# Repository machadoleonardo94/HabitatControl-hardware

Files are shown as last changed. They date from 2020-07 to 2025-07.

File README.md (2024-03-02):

## Hardware files for running HabitatControl Firmware
### ** Version 1 contains 5 PWM open drain channels, 2 NO relay channels, I2C 1" OLED display and DHT22 humidity and temperature sensor;
### ** Version 3 contains 6 PWM 700mA current limited LED drivers and I2C 1" OLED display
### Both versions are controlled via webserver for schedule of light intensity and data sampling





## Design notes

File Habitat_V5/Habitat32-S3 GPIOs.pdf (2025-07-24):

Features:
- Microcontrolador ESP32-S3-WROOM
- 2 Canais PWM 705mA CC XL4001
- 4 Canais PWM 620mA CC XL4001
- 1 Canal PWM Dreno aberto 10A
- 1 Enable master p/ drivers
- 1 Sensor 1Wire Temperatura DS18B20
- LED Debug WS2812B + Saída 5V 600mA
- Sem horário
- Sem internet
- Manual
- Automático
- I2C 1
- Display 3V3 (0x3C)
- ADS1115 (0x48)
■ Tensão de entrada atenuado 11x ■ Nível de fluído pull-up 330
■ Alerta fluído baixo pull-up 2k2
■ Livre pull-up 2k2
- SHT40 (0x44)
■ Temperatura ±0.2 ºC
■ Umidade ±1.8%
- RTC (0x68)
- I2C 2
- Display 5V (0xFF)

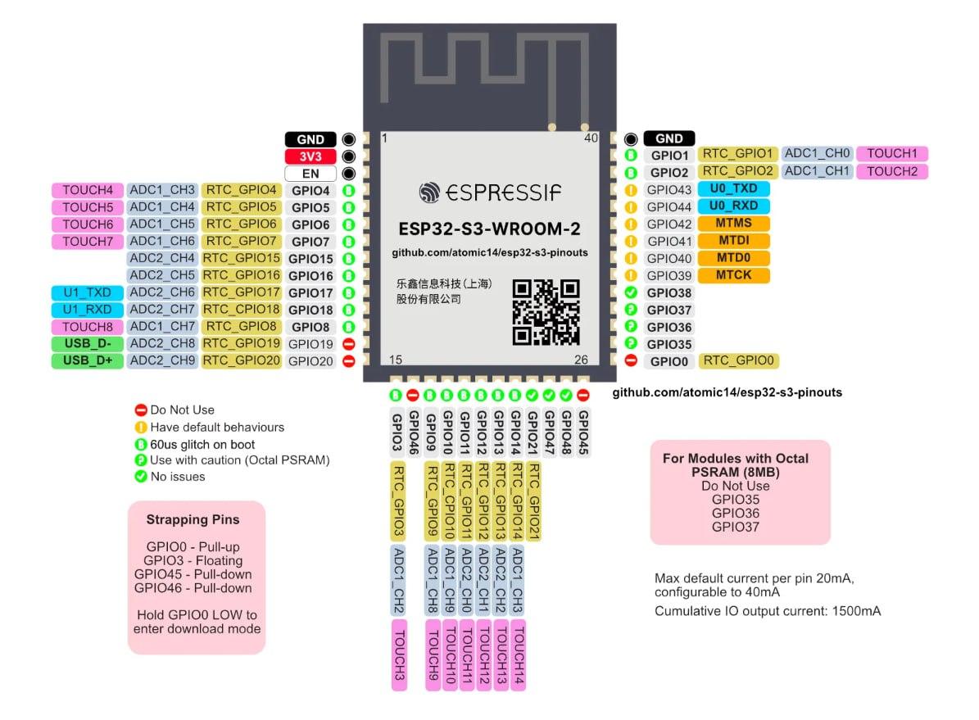
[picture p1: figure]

IO | Input | Output | Use | Notes
0 | 10k UP | OK | Prog | Boot mode, 60us glitch on boot
1 | OK | OK | | 60us glitch on boot
2 | OK | OK | | 60us glitch on boot
3 | Floating | X | X | Strapping, 60us glitch on boot
4 | OK | OK | CH1 | 60us glitch on boot
5 | OK | OK | CH2 | 60us glitch on boot
6 | OK | OK | CH3 | 60us glitch on boot
7 | OK | OK | CH4 | 60us glitch on boot
8 | OK | OK | I2C SCL 2 | 60us glitch on boot
9 | OK | OK | I2C SDA 2 | 60us glitch on boot
10 | OK | OK | I2C SCL 1 | 60us glitch on boot
11 | OK | OK | I2C SDA 1 | 60us glitch on boot
12 | OK | OK | Opto | 60us glitch on boot
13 | OK | OK | 1Wire | 60us glitch on boot
14 | OK | OK | CH7 | 60us glitch on boot
15 | OK | OK | CH5 | 60us glitch on boot
16 | OK | OK | CH6 | 60us glitch on boot
17 | OK | OK | WS2812B | 60us glitch on boot
18 | OK | OK | Free | 60us glitch on boot
19 | OK | OK | USB D- | Do not use as GPIO
20 | OK | OK | USB D+ | Do not use as GPIO
21 | OK | OK | Relay 1 | Stable GPIO
35 | Floating | X | PSRAM | Embedded RAM
36 | Floating | X | PSRAM | Embedded RAM
37 | Floating | X | PSRAM | Embedded RAM
38 | OK | OK | Enable Master | Stable GPIO
39 | X | X | X | MTCK

40 | X | X | X | MTDO
41 | X | X | X | MTDI
42 | X | X | X | MTMS
43 | OK | X | TX | Reserved TX
44 | | OK | RX | Reserved RX
45 | Floating | X | X | Strapping
46 | Floating | X | X | Strapping
47 | OK | OK | Free | Stable GPIO
48 | OK | OK | Free | Stable GPIO

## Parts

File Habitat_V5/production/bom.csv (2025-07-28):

Designator | Footprint | Quantity | Value | LCSC Part #
C1, C10, C11, C12, C13, C14, C15, C16, C17, C19, C20, C21, C23, C24, C25, C3, C4, C5, C6, C9 | C_Elec_6.3x7.7 | 20 | 220uF | C7471881
C2, CD2, CD4, CD5, CD7, CD8 | 0805 | 6 | 10u | C77075
C22 | C_Elec_6.3x7.7 | 1 | 100uF | C99837
C26, CD6 | 0805 | 2 | 100n | C1711
C7, C8, CD1, CD3 | 0805 | 4 | 100n | C2909631
D1 | LED_WS2812B_PLCC4_5.0x5.0mm_P3.2mm | 1 | WS2812B | 1
D10, D12, D13, D14, D16, D3, D8, D9 | D_SMA | 8 | SS14 | C2909920
D11, D4, D6 | 0805 | 3 | LED | C84256
D15, D5, D7 | D_SOD-123 | 3 | 1N4148W | C82544
D17, D18, D19, D20 | SOT-23 | 4 | BAT54S | C47546
D2 | D_MiniMELF | 1 | D_Zener | C181075
F1 | 1206 | 1 | Polyfuse | C22446878
J1, J3, J4 | PhoenixContact_MSTBA_2,5_4-G-5,08_1x04_P5.08mm_Horizontal | 3 | Conn_01x04_Socket
J2, J5, RELAY1 | PhoenixContact_MSTBA_2,5_3-G-5,08_1x03_P5.08mm_Horizontal | 3 | Conn_01x03_Socket
K1 | Relay_SPDT_Hongfa_JQC-3FF_0XX-1Z | 1 | Relay_SPDT
L1, L3, L4, L5, L6, L7, L8 | L_Sunlord_SWPA4010S | 7 | 33u | C167885
L2 | 0805 | 1 | 22n | C167885
OLED1, OLED2, SERIAL1 | Hirose_DF13C_CL535-0404-8-51_1x04-1MP_P1.25mm_Vertical | 3 | Conn_01x04_Socket | C7433470
OPTO1 | PhoenixContact_MSTBA_2,5_3-G-5,08_1x03_P5.08mm_Horizontal | 1 | Conn_01x03_Pin | 1
PROG1, RST1 | SW_SPST_PTS647_Sx38 | 2 | SW_Push | C455246
PWM1, S1, S2, TH1, VDC2 | PhoenixContact_MSTBA_2,5_2-G-5,08_1x02_P5.08mm_Horizontal | 5 | Conn_01x02_Pin | 1
Q1 | SOT-223-3_TabPin2 | 1 | PMOS | C154901
Q10, Q11, Q12, Q13, Q14, Q15, Q16, Q17, Q2, Q4, Q5, Q6, Q7, Q8, Q9 | SOT-23 | 15 | 2N7002K | C65189
Q3 | TO-252-2 | 1 | 40N02
R1, R10, R12, R13, R20, R25, R26, R27, R29, R32, R33, R34, R35, R36, R37, R38, R39, R40, R41, R42, R43, R44, R8 | 0805 | 23 | 10k | C17414
R11, R14, R16, R19 | 1206 | 4 | 0R22 | C2683384
R15, R24, R30, R31 | 0805 | 4 | 330 | C17630
R17, R18 | 1206 | 2 | 0R25 | C2932845
R2, R9 | 0805 | 2 | 1k | C95781
R21, R23, R3, R4, R5, R6, R7 | 0805 | 7 | 2k2 | C17520
R22, R28 | 0805 | 2 | 100k | C149504
RTC1 | RTC | 1 | Conn_01x04_Socket | 1
SHT40 | PinHeader_1x04_P2.54mm_Vertical | 1 | Conn_01x04_Socket | 1
U1 | SOIC-8_3.9x4.9mm_P1.27mm | 1 | XL1509-5V | C2681227
U10, U4, U5, U7, U8, U9 | ESOP-8_L4.9-W3.9-P1.27-LS6.0-BL-EP | 6 | ~ | C2988027
U11 | TSSOP-10_3x3mm_P0.5mm | 1 | ADS1115IDGS | C37593
U2 | SOT-23-5 | 1 | AP2112K-3.3 | C51118
U3 | SMDIP-4_W7.62mm | 1 | PC817 | C5451664
U6 | ESP32-S3-WROOM-1 | 1 | ESP32-S3-WROOM-1
VDC1 | BarrelJack_Horizontal | 1 | Barrel_Jack_Switch | C720557

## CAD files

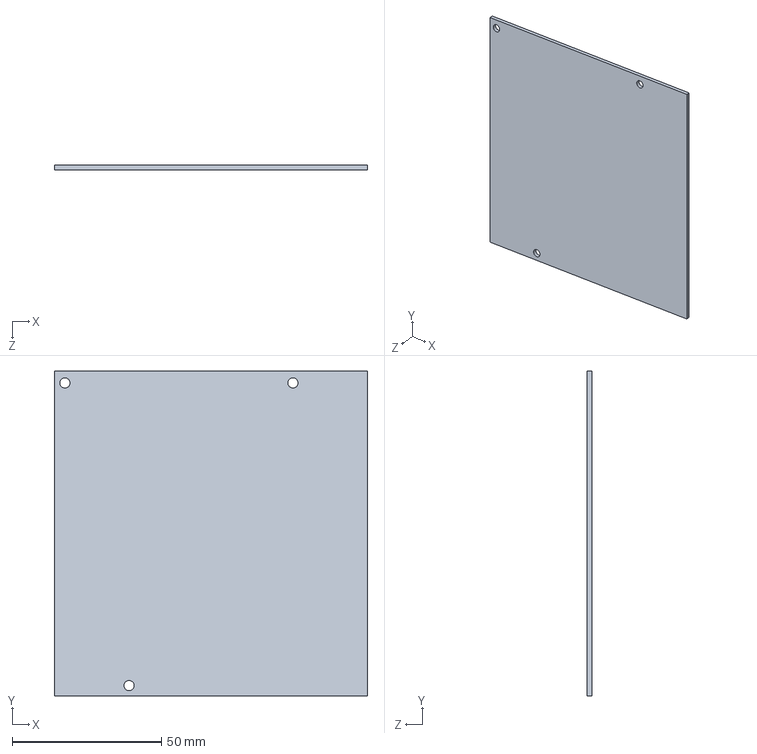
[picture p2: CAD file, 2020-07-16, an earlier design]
Habitat_V1/HabitatControl-noholes.step
105.0 x 109.0 x 1.59 mm

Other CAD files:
Habitat_V1/HabitatControl.step

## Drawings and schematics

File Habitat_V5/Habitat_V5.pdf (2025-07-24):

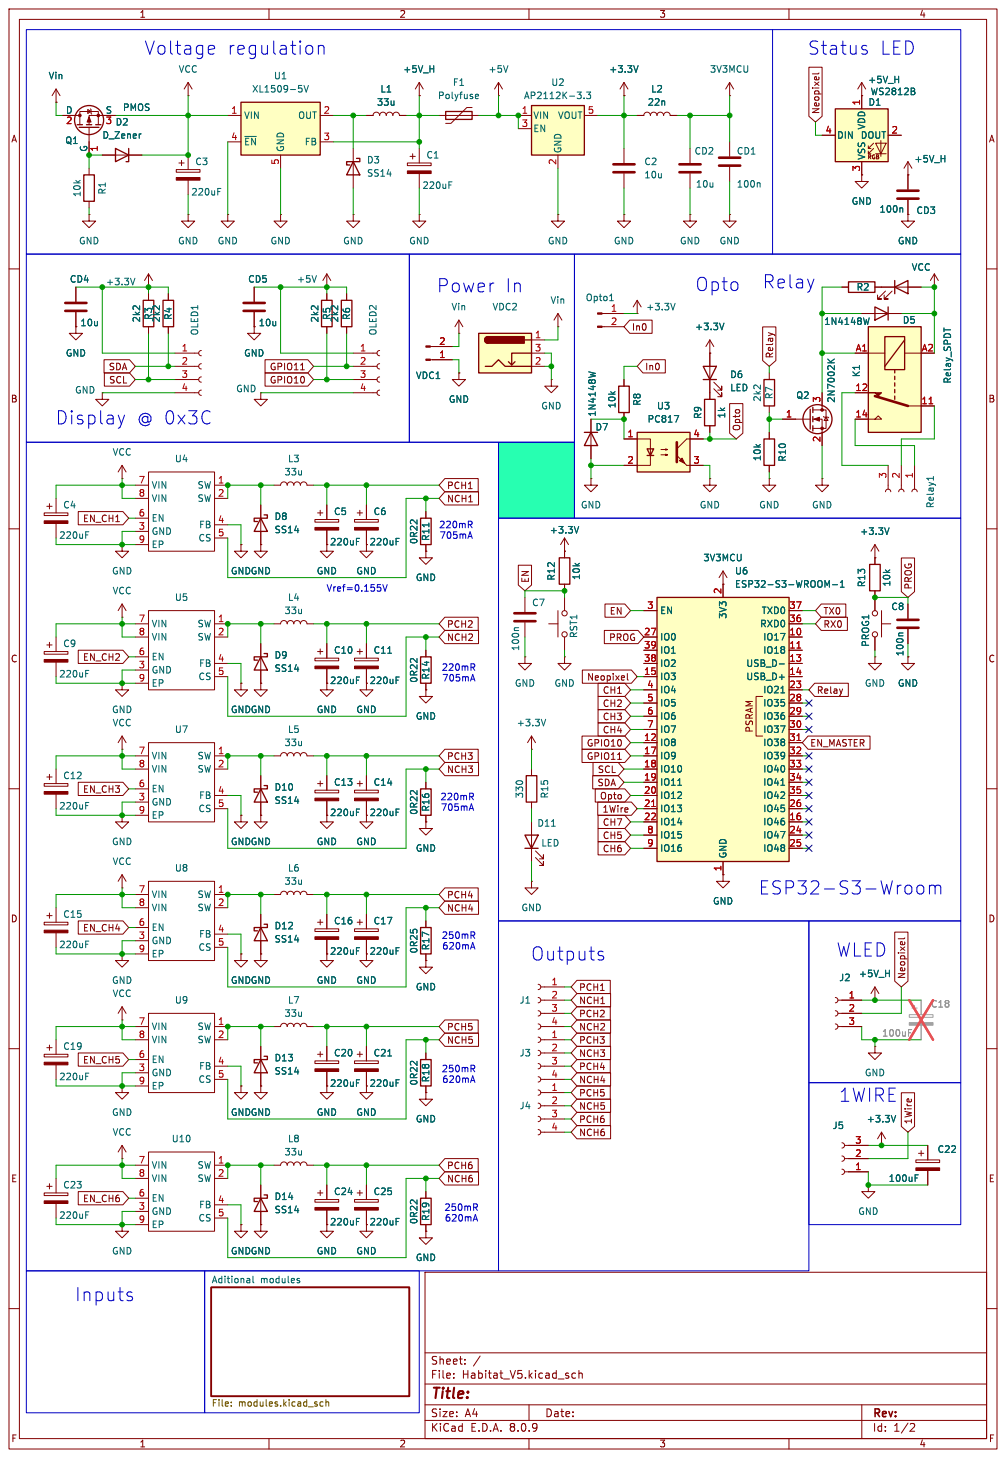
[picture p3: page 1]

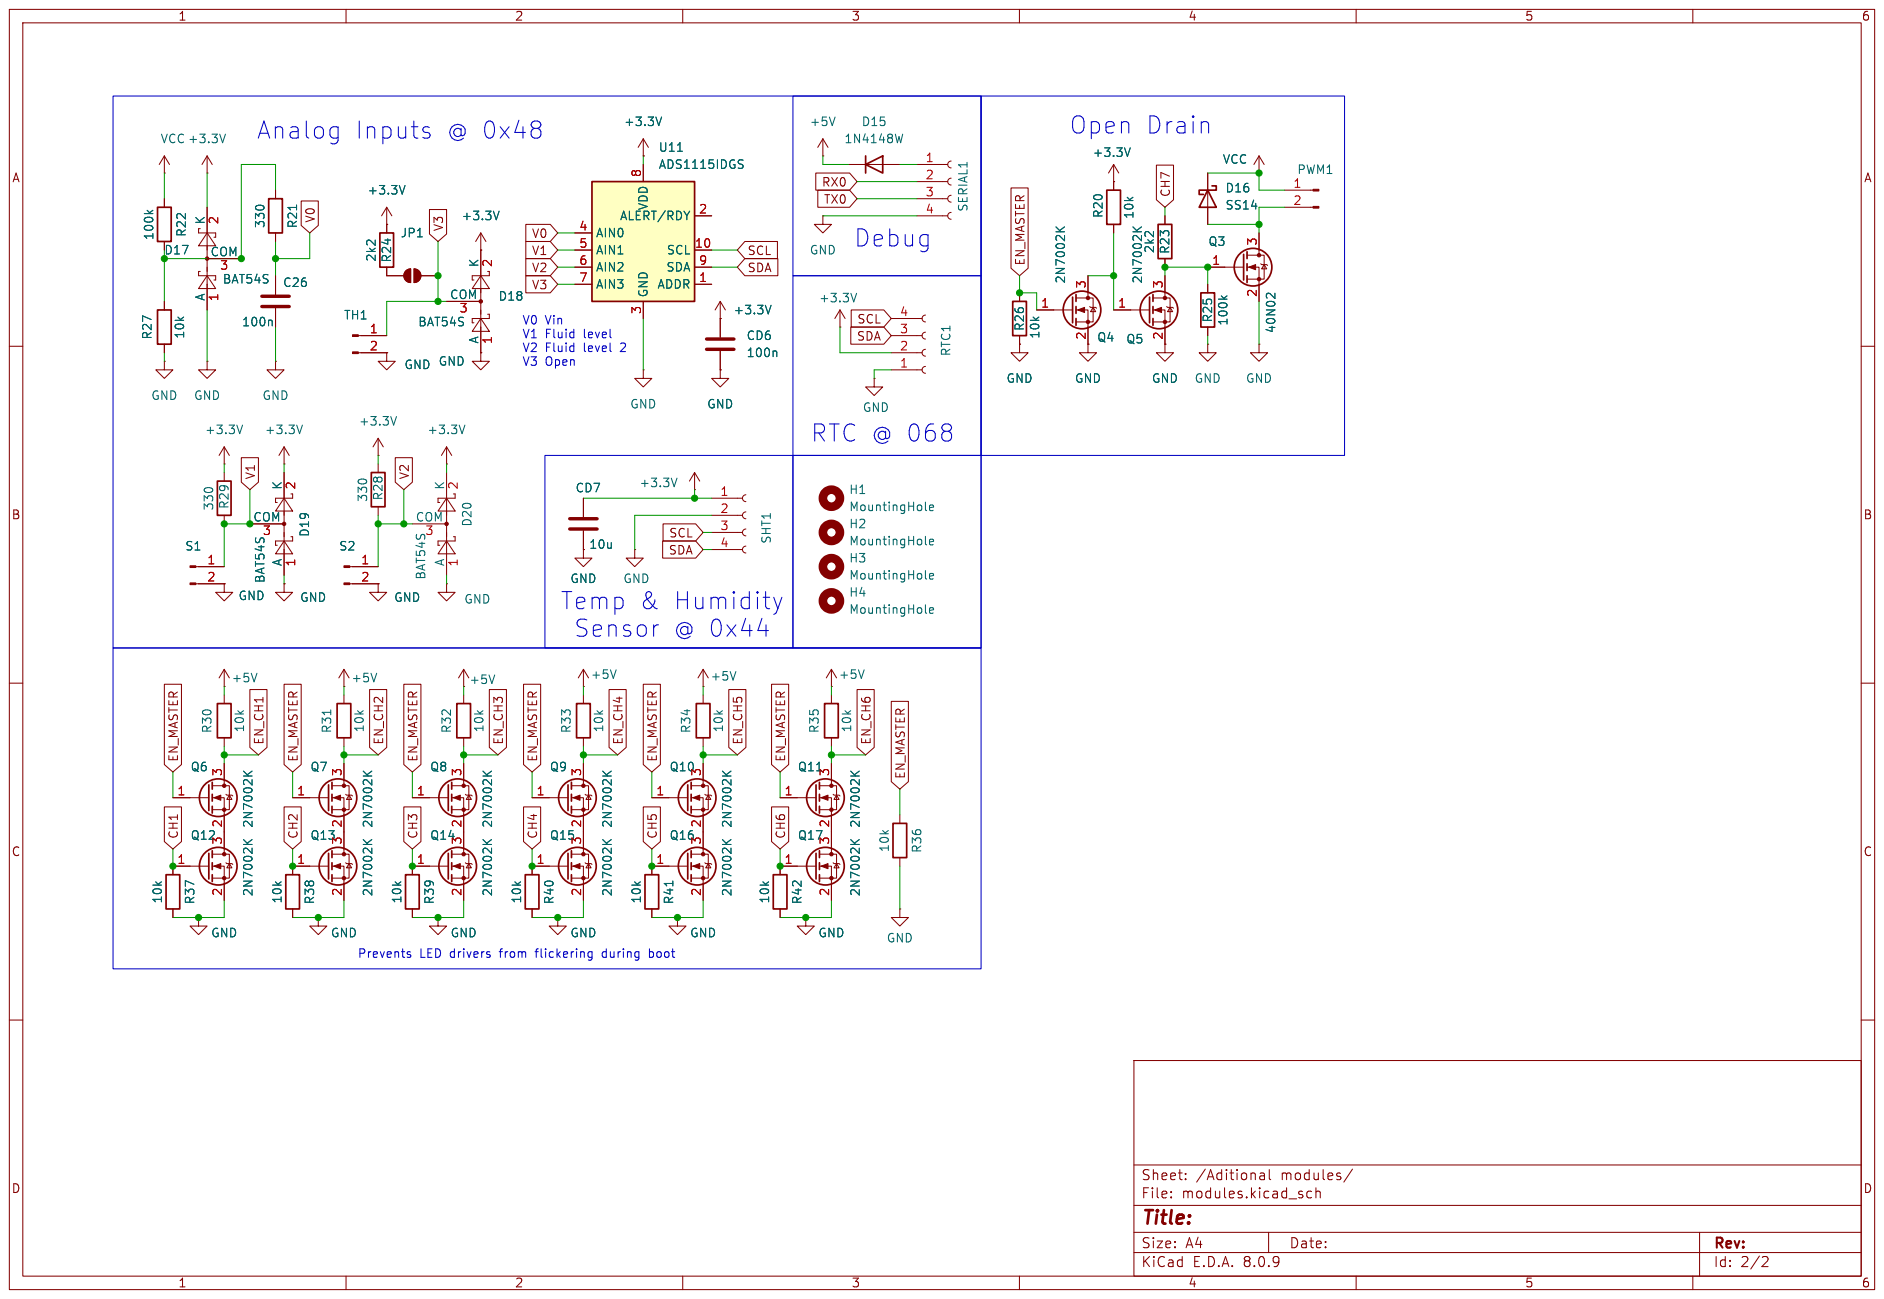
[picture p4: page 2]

3 AIN0 4 AIN1 5 AIN2 6 AIN3 7 VDD
ADDR 1 SCL 10 ALERT/RDY 2 GND

V0 Vin V1 Fluid level V2 Fluid level 2 V3 Open

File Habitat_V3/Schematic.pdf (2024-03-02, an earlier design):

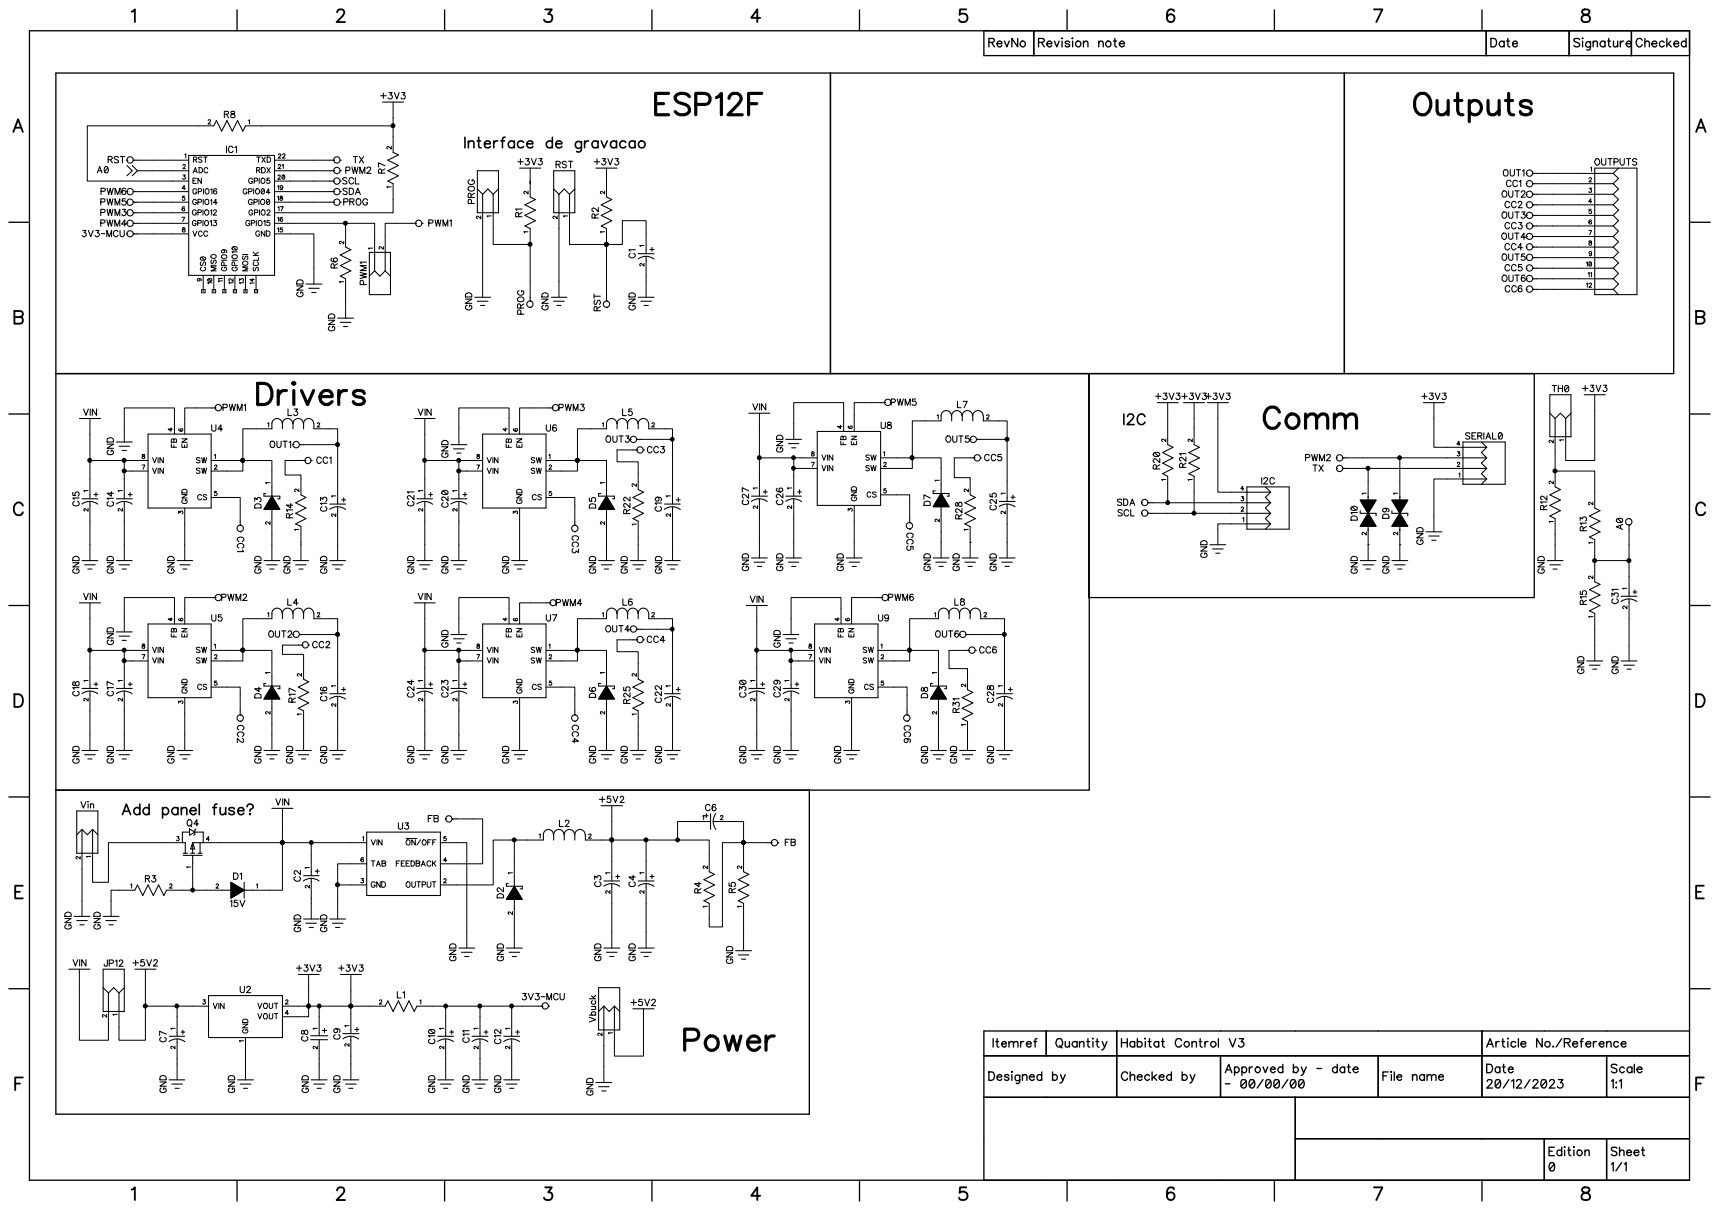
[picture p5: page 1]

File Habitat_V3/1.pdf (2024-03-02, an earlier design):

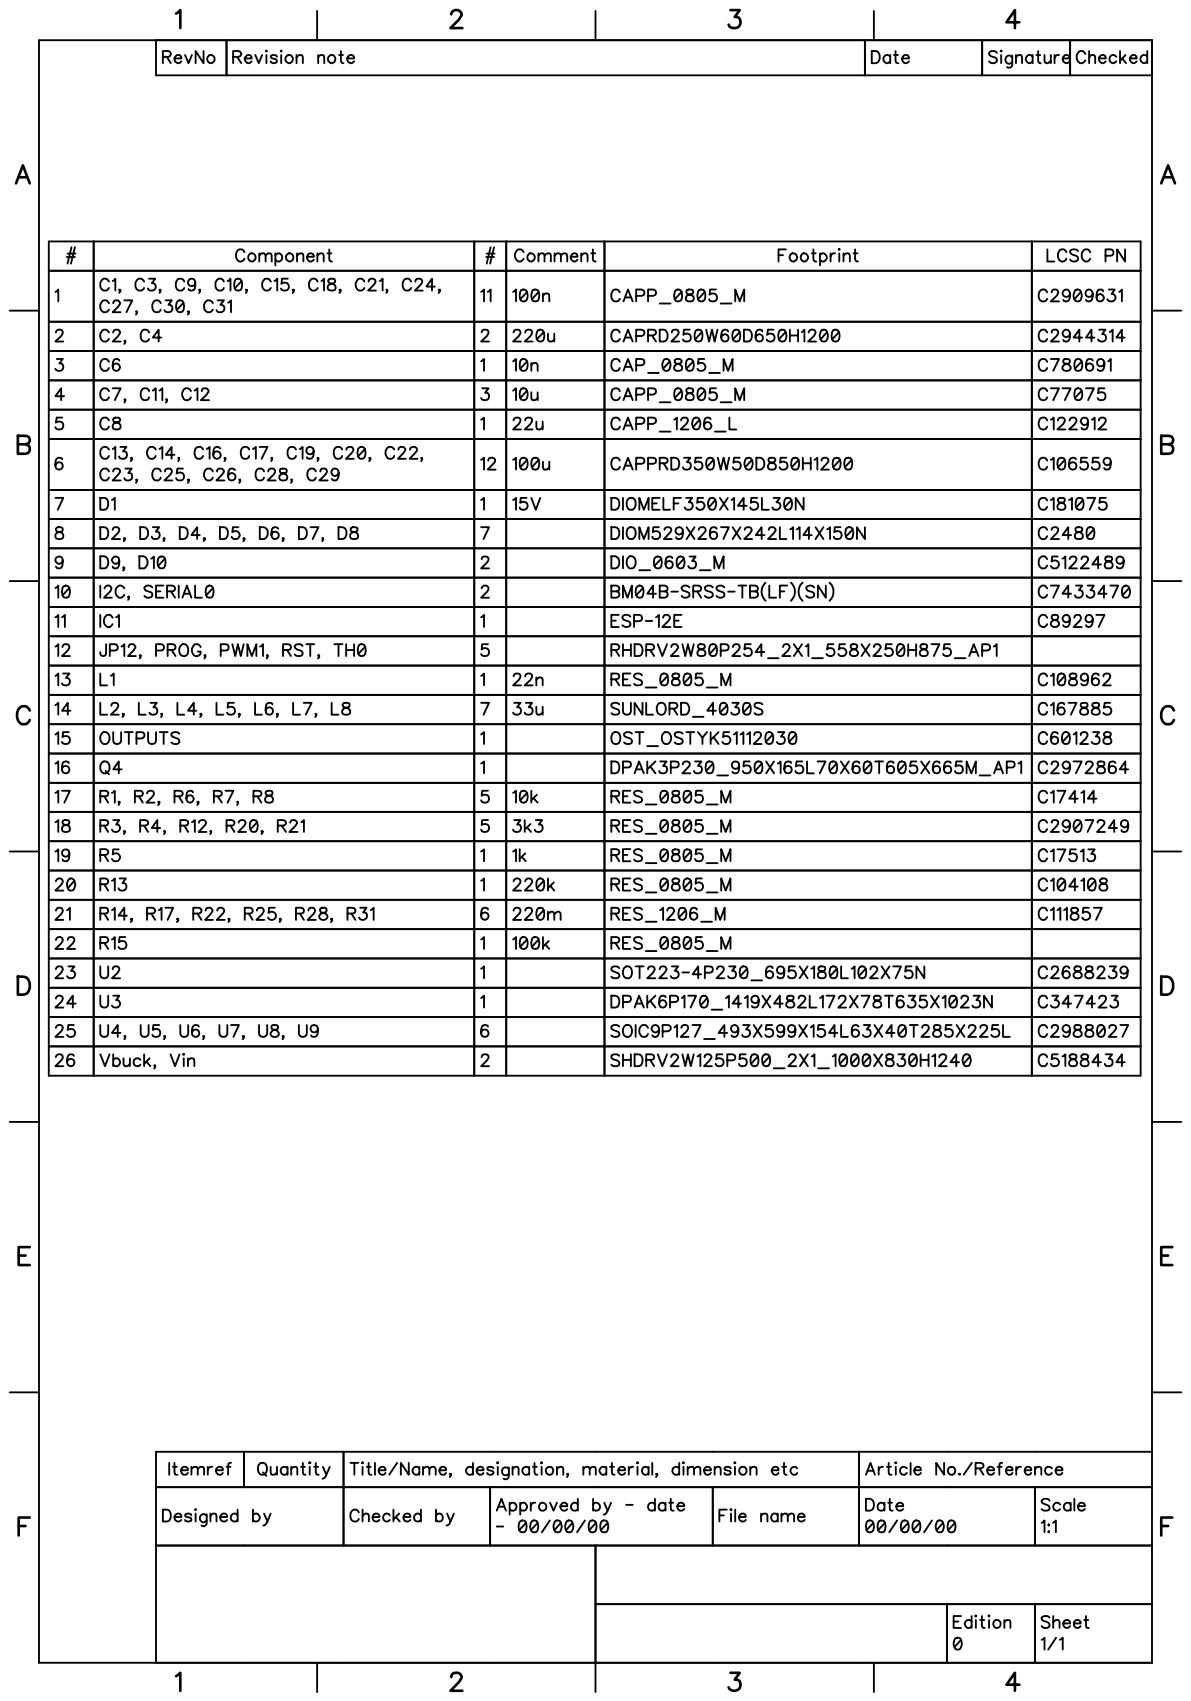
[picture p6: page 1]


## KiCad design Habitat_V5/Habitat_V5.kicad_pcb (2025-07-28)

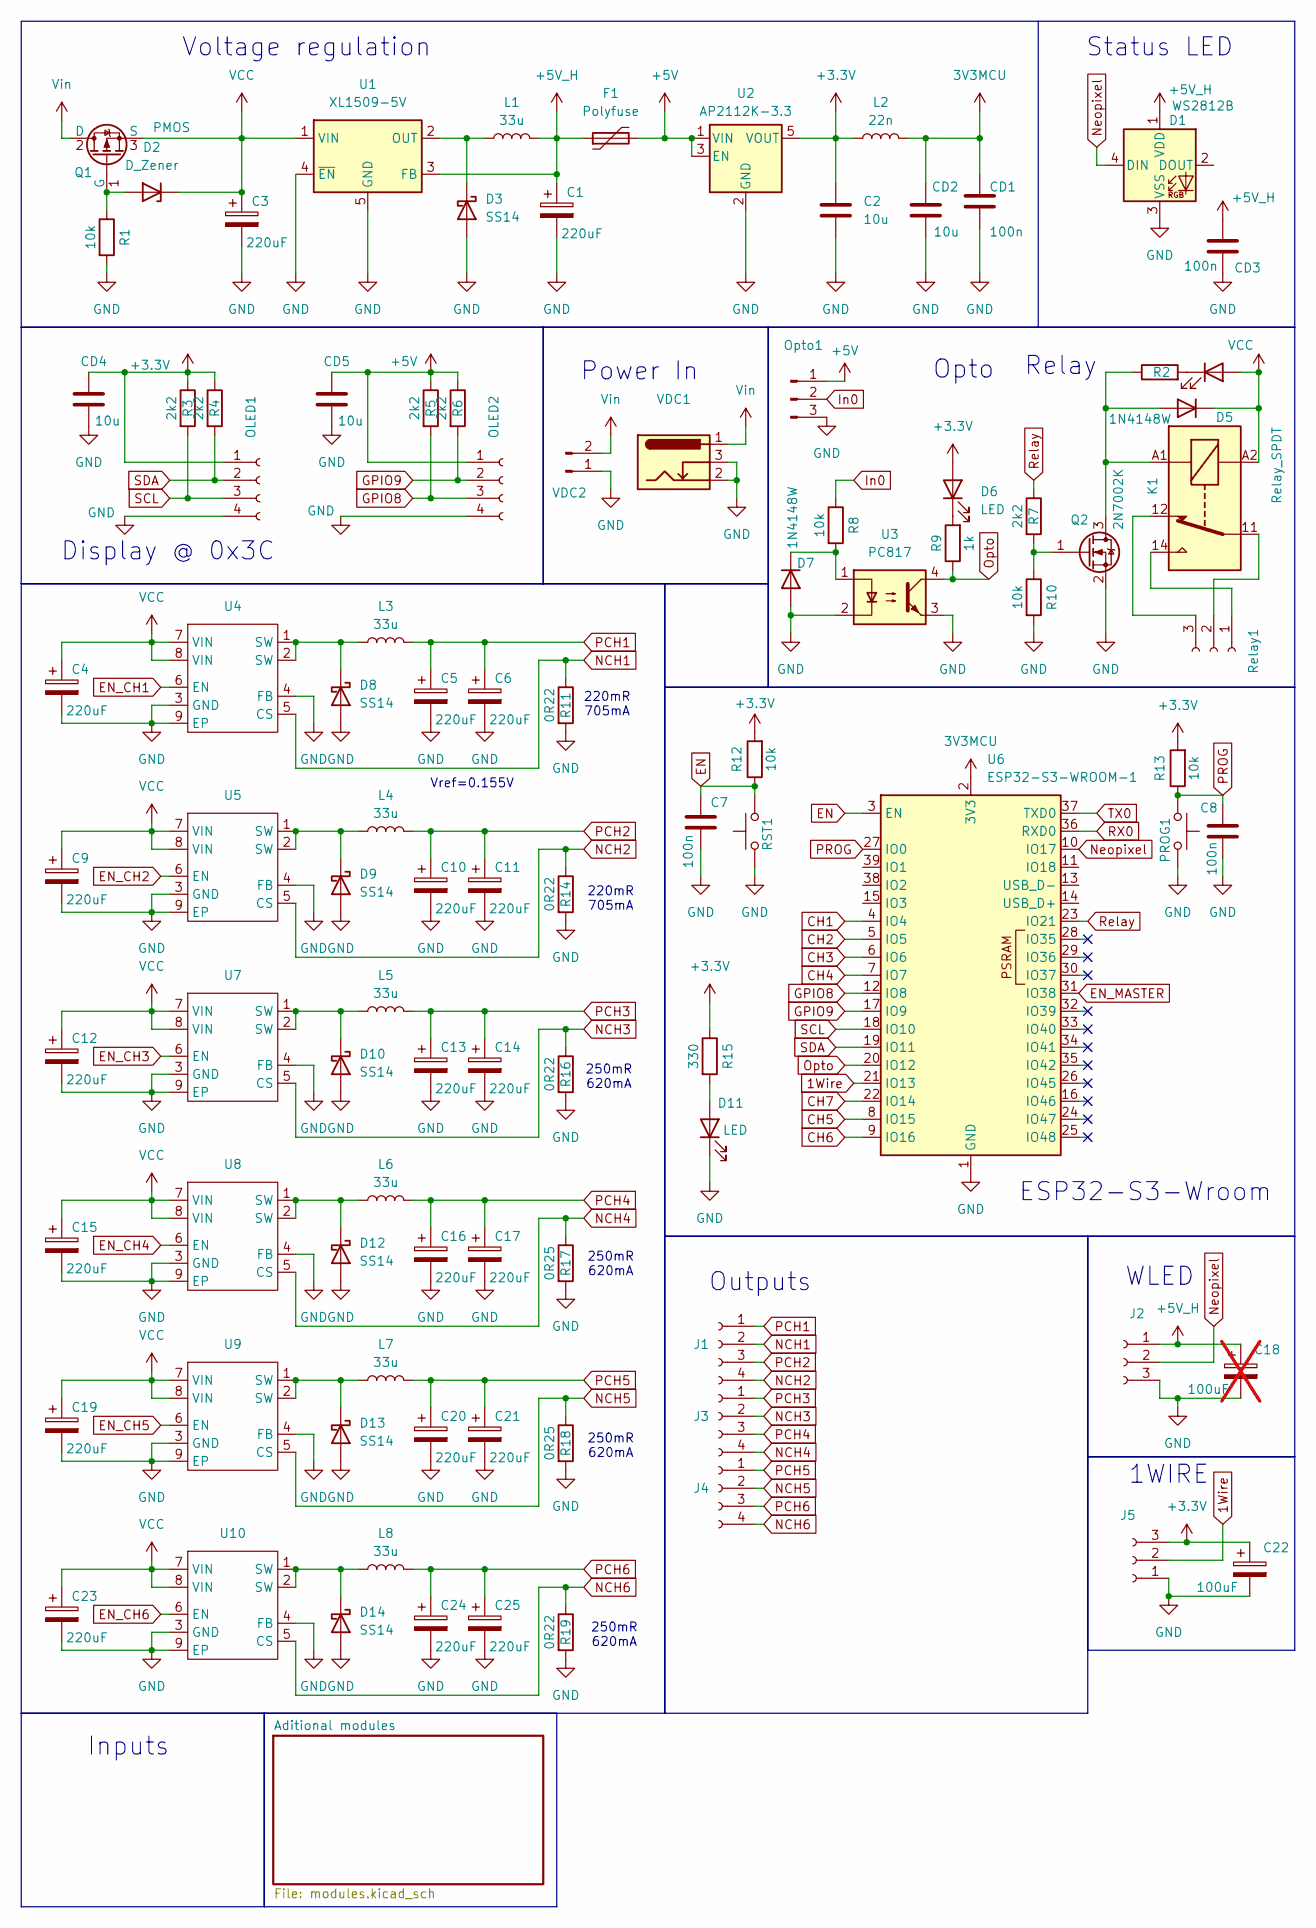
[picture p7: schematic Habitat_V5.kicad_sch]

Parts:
C1, C3, C4, C5, C6, C9, C10, C11, C12, C13, C14, C15, C16, C17, C19, C20, C21, C23, C24, C25: 220uF; C_Elec_6.3x7.7; LCSC C7471881
C2: 10u; C_0805_2012Metric; LCSC C77075
C7, C8: 100n; C_0805_2012Metric; LCSC C2909631
C18: 100uF; C_Elec_6.3x7.7; LCSC C99837; not fitted
C22: 100uF; C_Elec_6.3x7.7; LCSC C99837
CD1, CD3: 100n; C_0805_2012Metric; LCSC C2909631
CD2, CD4, CD5: 10u; C_0805_2012Metric; LCSC C77075
D1: WS2812B; LED_WS2812B_PLCC4_5.0x5.0mm_P3.2mm; LCSC 1
D2: D_Zener; D_MiniMELF; LCSC C181075
D3, D8, D9, D10, D12, D13, D14: SS14; D_SMA; LCSC C2909920
D4, D6, D11: LED; LED_0805_2012Metric_Pad1.15x1.40mm_HandSolder; LCSC C84256
D5, D7: 1N4148W; D_SOD-123; LCSC C82544
F1: Polyfuse; Fuse_1206_3216Metric_Pad1.42x1.75mm_HandSolder; LCSC C22446878
J1, J3, J4: Conn_01x04_Socket; PhoenixContact_MSTBA_2,5_4-G-5,08_1x04_P5.08mm_Horizontal
J2, J5: Conn_01x03_Socket; PhoenixContact_MSTBA_2,5_3-G-5,08_1x03_P5.08mm_Horizontal
K1: Relay_SPDT; Relay_SPDT_Hongfa_JQC-3FF_0XX-1Z
L1, L3, L4, L5, L6, L7, L8: 33u; L_Sunlord_SWPA4010S; LCSC C167885
L2: 22n; L_0805_2012Metric; LCSC C167885
OLED1, OLED2: Conn_01x04_Socket; Hirose_DF13C_CL535-0404-8-51_1x04-1MP_P1.25mm_Vertical; LCSC C7433470
Opto1: Conn_01x03_Pin; PhoenixContact_MSTBA_2,5_3-G-5,08_1x03_P5.08mm_Horizontal; LCSC 1
PROG1: SW_Push; SW_SPST_PTS647_Sx38; LCSC C455246
Q1: PMOS; SOT-223-3_TabPin2; LCSC C154901
Q2: 2N7002K; SOT-23; LCSC C65189
R1, R8, R10, R12, R13: 10k; R_0805_2012Metric; LCSC C17414
R2, R9: 1k; R_0805_2012Metric; LCSC C95781
R3, R4, R5, R6, R7: 2k2; R_0805_2012Metric; LCSC C17520
R11, R14, R16, R19: 0R22; R_1206_3216Metric; LCSC C2683384
R15: 330; R_0805_2012Metric; LCSC C17630
R17, R18: 0R25; R_1206_3216Metric; LCSC C2932845
RST1: SW_Push; SW_SPST_PTS647_Sx38; LCSC C455246
Relay1: Conn_01x03_Socket; PhoenixContact_MSTBA_2,5_3-G-5,08_1x03_P5.08mm_Horizontal
U1: XL1509-5V; SOIC-8_3.9x4.9mm_P1.27mm; LCSC C2681227
U2: AP2112K-3.3; SOT-23-5; LCSC C51118
U3: PC817; SMDIP-4_W7.62mm; LCSC C5451664
U4, U5, U7, U8, U9, U10: ESOP-8_L4.9-W3.9-P1.27-LS6.0-BL-EP; Manufacturer Part XL4001E1; LCSC Part Name XL4001E1
U6: ESP32-S3-WROOM-1
VDC1: Barrel_Jack_Switch; BarrelJack_Horizontal; LCSC C720557
VDC2: Conn_01x02_Pin; PhoenixContact_MSTBA_2,5_2-G-5,08_1x02_P5.08mm_Horizontal; LCSC 1

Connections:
1Wire: J5.2, U6.21 (IO13)
3V3MCU: CD1.1, CD2.1, L2.2, U6.2 (3V3)
+3.3V: C2.1, C22.1, CD4.1, D6.2 (A), J5.3, L2.1, OLED1.1, R3.1, R4.1, R12.2, R13.2, R15.1, U2.5 (VOUT); also elsewhere on the board
+5V: CD5.1, F1.2, OLED2.1, Opto1.1, R5.1, R6.1, U2.1 (VIN), U2.3 (EN); also elsewhere on the board
+5V_H: C1.1, C18.1, CD3.1, D1.1 (VDD), F1.1, J2.1, L1.2, U1.3 (FB)
CH1: U6.4 (IO4); also elsewhere on the board
CH2: U6.5 (IO5); also elsewhere on the board
CH3: U6.6 (IO6); also elsewhere on the board
CH4: U6.7 (IO7); also elsewhere on the board
CH5: U6.8 (IO15); also elsewhere on the board
CH6: U6.9 (IO16); also elsewhere on the board
CH7: U6.22 (IO14); also elsewhere on the board
EN: C7.1, R12.1, RST1.2, U6.3 (EN)
EN_CH1: U4.6 (EN); also elsewhere on the board
EN_CH2: U5.6 (EN); also elsewhere on the board
EN_CH3: U7.6 (EN); also elsewhere on the board
EN_CH4: U8.6 (EN); also elsewhere on the board
EN_CH5: U9.6 (EN); also elsewhere on the board
EN_CH6: U10.6 (EN); also elsewhere on the board
EN_MASTER: U6.31 (IO38); also elsewhere on the board
GND: C1.2, C2.2, C3.2, C4.2, C5.2, C6.2, C7.2, C8.2, C9.2, C10.2, C11.2, C12.2, C13.2, C14.2, C15.2, C16.2, C17.2, C18.2, C19.2, C20.2, C21.2, C22.2, C23.2, C24.2, C25.2, CD1.2, CD2.2, CD3.2, CD4.2, CD5.2, D1.3 (VSS), D3.2 (A), D7.2 (A), D8.2 (A), D9.2 (A), D10.2 (A), D11.1 (K), D12.2 (A), D13.2 (A), D14.2 (A), J2.3, J5.1, OLED1.4, OLED2.4, Opto1.3, PROG1.1, Q2.2 (S), R1.2, R10.2, R11.2, R14.2, R16.2, R17.2, R18.2, R19.2, RST1.1, U1.4 (~EN), U1.5 (GND), U1.6 (GND), U1.7 (GND), U1.8 (GND), U2.2 (GND), U3.2, U3.3, U4.3 (GND), U4.4 (FB), U4.9 (EP), U5.3 (GND), U5.4 (FB), U5.9 (EP), U6.1 (GND), U6.40 (GND), U6.41 (GND), U7.3 (GND), U7.4 (FB), U7.9 (EP), U8.3 (GND), U8.4 (FB), U8.9 (EP), U9.3 (GND), U9.4 (FB), U9.9 (EP), U10.3 (GND), U10.4 (FB), U10.9 (EP), VDC1.2, VDC1.3, VDC2.1; also elsewhere on the board
GPIO8: OLED2.3, R5.2, U6.12 (IO8)
GPIO9: OLED2.2, R6.2, U6.17 (IO9)
In0: Opto1.2, R8.1
NCH1: J1.2, R11.1, U4.5 (CS)
NCH2: J1.4, R14.1, U5.5 (CS)
NCH3: J3.2, R16.1, U7.5 (CS)
NCH4: J3.4, R17.1, U8.5 (CS)
NCH5: J4.2, R18.1, U9.5 (CS)
NCH6: J4.4, R19.1, U10.5 (CS)
Neopixel: D1.4 (DIN), J2.2, U6.10 (IO17)
unnamed: D2.2 (A), Q1.1 (G), R1.1
unnamed: D3.1 (K), L1.1, U1.2 (OUT)
unnamed: D4.1 (K), R2.2
unnamed: D5.2 (A), K1.A1, Q2.3 (D), R2.1
unnamed: D6.1 (K), R9.2
unnamed: D7.1 (K), R8.2, U3.1
unnamed: D8.1 (K), L3.1, U4.1 (SW), U4.2 (SW)
unnamed: D9.1 (K), L4.1, U5.1 (SW), U5.2 (SW)
unnamed: D10.1 (K), L5.1, U7.1 (SW), U7.2 (SW)
unnamed: D11.2 (A), R15.2
unnamed: D12.1 (K), L6.1, U8.1 (SW), U8.2 (SW)
unnamed: D13.1 (K), L7.1, U9.1 (SW), U9.2 (SW)
unnamed: D14.1 (K), L8.1, U10.1 (SW), U10.2 (SW)
unnamed: Q2.1 (G), R7.2, R10.1
unnamed: K1.14, Relay1.1
unnamed: K1.11, Relay1.2
unnamed: K1.12, Relay1.3
Opto: R9.1, U3.4, U6.20 (IO12)
PCH1: C5.1, C6.1, J1.1, L3.2
PCH2: C10.1, C11.1, J1.3, L4.2
PCH3: C13.1, C14.1, J3.1, L5.2
PCH4: C16.1, C17.1, J3.3, L6.2
PCH5: C20.1, C21.1, J4.1, L7.2
PCH6: C24.1, C25.1, J4.3, L8.2
PROG: C8.1, PROG1.2, R13.1, U6.27 (IO0)
RX0: U6.36 (RXD0); also elsewhere on the board
Relay: R7.1, U6.23 (IO21)
SCL: OLED1.3, R3.2, U6.18 (IO10); also elsewhere on the board
SDA: OLED1.2, R4.2, U6.19 (IO11); also elsewhere on the board
TX0: U6.37 (TXD0); also elsewhere on the board
VCC: C3.1, C4.1, C9.1, C12.1, C15.1, C19.1, C23.1, D2.1 (K), D4.2 (A), D5.1 (K), K1.A2, Q1.3 (S), U1.1 (VIN), U4.7 (VIN), U4.8 (VIN), U5.7 (VIN), U5.8 (VIN), U7.7 (VIN), U7.8 (VIN), U8.7 (VIN), U8.8 (VIN), U9.7 (VIN), U9.8 (VIN), U10.7 (VIN), U10.8 (VIN); also elsewhere on the board
Vin: Q1.2 (D), VDC1.1, VDC2.2

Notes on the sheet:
250mR 620mA
WLED
Power In
220mR 705mA
Status LED
ESP32-S3-Wroom
Display @ 0x3C
Outputs
Relay
Inputs
1WIRE
Voltage regulation
Vref=0.155V
Opto

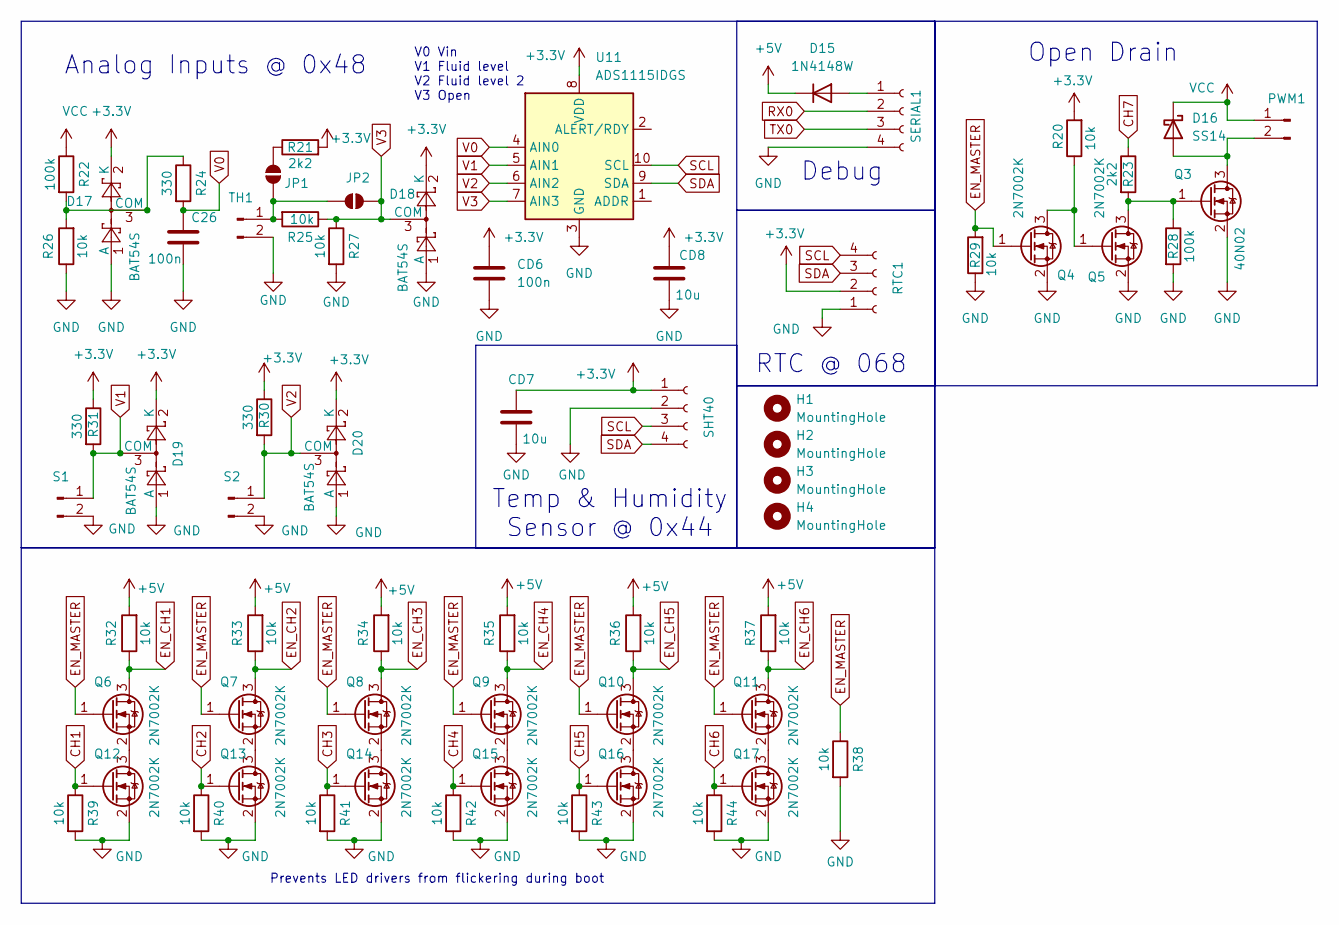
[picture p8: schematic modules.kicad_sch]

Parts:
C26: 100n; C_0805_2012Metric; LCSC C1711
CD6: 100n; C_0805_2012Metric; LCSC C1711
CD7, CD8: 10u; C_0805_2012Metric; LCSC C77075
D15: 1N4148W; D_SOD-123; LCSC C82544
D16: SS14; D_SMA; LCSC C2909920
D17, D18, D19, D20: BAT54S; SOT-23; LCSC C47546
H1, H2, H3, H4: MountingHole; MountingHole_3.2mm_M3
JP1, JP2: SolderJumper_2_Open; SolderJumper-2_P1.3mm_Open_RoundedPad1.0x1.5mm
PWM1: Conn_01x02_Pin; PhoenixContact_MSTBA_2,5_2-G-5,08_1x02_P5.08mm_Horizontal; LCSC 1
Q3: 40N02; TO-252-2
Q4, Q5, Q6, Q7, Q8, Q9, Q10, Q11, Q12, Q13, Q14, Q15, Q16, Q17: 2N7002K; SOT-23; LCSC C65189
R20, R25, R26, R27, R29, R32, R33, R34, R35, R36, R37, R38, R39, R40, R41, R42, R43, R44: 10k; R_0805_2012Metric; LCSC C17414
R21, R23: 2k2; R_0805_2012Metric; LCSC C17520
R22, R28: 100k; R_0805_2012Metric; LCSC C149504
R24, R30, R31: 330; R_0805_2012Metric; LCSC C17630
RTC1: Conn_01x04_Socket; RTC; LCSC 1
S1, S2: Conn_01x02_Pin; PhoenixContact_MSTBA_2,5_2-G-5,08_1x02_P5.08mm_Horizontal; LCSC 1
SERIAL1: Conn_01x04_Socket; Hirose_DF13C_CL535-0404-8-51_1x04-1MP_P1.25mm_Vertical; LCSC C7433470
SHT40: Conn_01x04_Socket; PinHeader_1x04_P2.54mm_Vertical; LCSC 1
TH1: Conn_01x02_Pin; PhoenixContact_MSTBA_2,5_2-G-5,08_1x02_P5.08mm_Horizontal; LCSC 1
U11: ADS1115IDGS; TSSOP-10_3x3mm_P0.5mm; LCSC C37593

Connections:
+3.3V: CD6.1, CD7.1, CD8.1, D17.2 (K), D18.2 (K), D19.2 (K), D20.2 (K), R20.2, R21.2, R30.1, R31.1, RTC1.2, SHT40.1, U11.8 (VDD); also elsewhere on the board
+5V: D15.1 (K), R32.2, R33.2, R34.2, R35.2, R36.2, R37.2; also elsewhere on the board
CH1: Q12.1 (G), R39.1; also elsewhere on the board
CH2: Q13.1 (G), R40.1; also elsewhere on the board
CH3: Q14.1 (G), R41.1; also elsewhere on the board
CH4: Q15.1 (G), R42.1; also elsewhere on the board
CH5: Q16.1 (G), R43.1; also elsewhere on the board
CH6: Q17.1 (G), R44.1; also elsewhere on the board
CH7: R23.1; also elsewhere on the board
EN_CH1: Q6.3 (D), R32.1; also elsewhere on the board
EN_CH2: Q7.3 (D), R33.1; also elsewhere on the board
EN_CH3: Q8.3 (D), R34.1; also elsewhere on the board
EN_CH4: Q9.3 (D), R35.1; also elsewhere on the board
EN_CH5: Q10.3 (D), R36.1; also elsewhere on the board
EN_CH6: Q11.3 (D), R37.1; also elsewhere on the board
EN_MASTER: Q4.1 (G), Q6.1 (G), Q7.1 (G), Q8.1 (G), Q9.1 (G), Q10.1 (G), Q11.1 (G), R29.2, R38.1; also elsewhere on the board
GND: C26.2, CD6.2, CD7.2, CD8.2, D17.1 (A), D18.1 (A), D19.1 (A), D20.1 (A), Q3.2 (S), Q4.2 (S), Q5.2 (S), Q12.2 (S), Q13.2 (S), Q14.2 (S), Q15.2 (S), Q16.2 (S), Q17.2 (S), R26.1, R27.2, R28.2, R29.1, R38.2, R39.2, R40.2, R41.2, R42.2, R43.2, R44.2, RTC1.1, S1.2, S2.2, SERIAL1.4, SHT40.2, TH1.2, U11.3 (GND); also elsewhere on the board
unnamed: D15.2 (A), SERIAL1.1
unnamed: D16.2 (A), PWM1.2, Q3.3 (D)
unnamed: D17.3 (COM), R22.2, R24.1, R26.2
unnamed: JP1.1 (A), JP2.1 (A), R25.2, TH1.1
unnamed: JP1.2 (B), R21.1
unnamed: Q3.1 (G), Q5.3 (D), R23.2, R28.1
unnamed: Q4.3 (D), Q5.1 (G), R20.1
unnamed: Q10.2 (S), Q16.3 (D)
unnamed: Q11.2 (S), Q17.3 (D)
unnamed: Q6.2 (S), Q12.3 (D)
unnamed: Q7.2 (S), Q13.3 (D)
unnamed: Q8.2 (S), Q14.3 (D)
unnamed: Q9.2 (S), Q15.3 (D)
RX0: SERIAL1.2; also elsewhere on the board
SCL: RTC1.4, SHT40.3, U11.10 (SCL); also elsewhere on the board
SDA: RTC1.3, SHT40.4, U11.9 (SDA); also elsewhere on the board
TX0: SERIAL1.3; also elsewhere on the board
V0: C26.1, R24.2, U11.4 (AIN0)
V1: D19.3 (COM), R31.2, S1.1, U11.5 (AIN1)
V2: D20.3 (COM), R30.2, S2.1, U11.6 (AIN2)
V3: D18.3 (COM), JP2.2 (B), R25.1, R27.1, U11.7 (AIN3)
VCC: D16.1 (K), PWM1.1, R22.1; also elsewhere on the board

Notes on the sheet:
Analog Inputs @ 0x48
RTC @ 068
Debug
Open Drain
Prevents LED drivers from flickering during boot
Temp & Humidity Sensor @ 0x44
V0 Vin V1 Fluid level V2 Fluid level 2 V3 Open

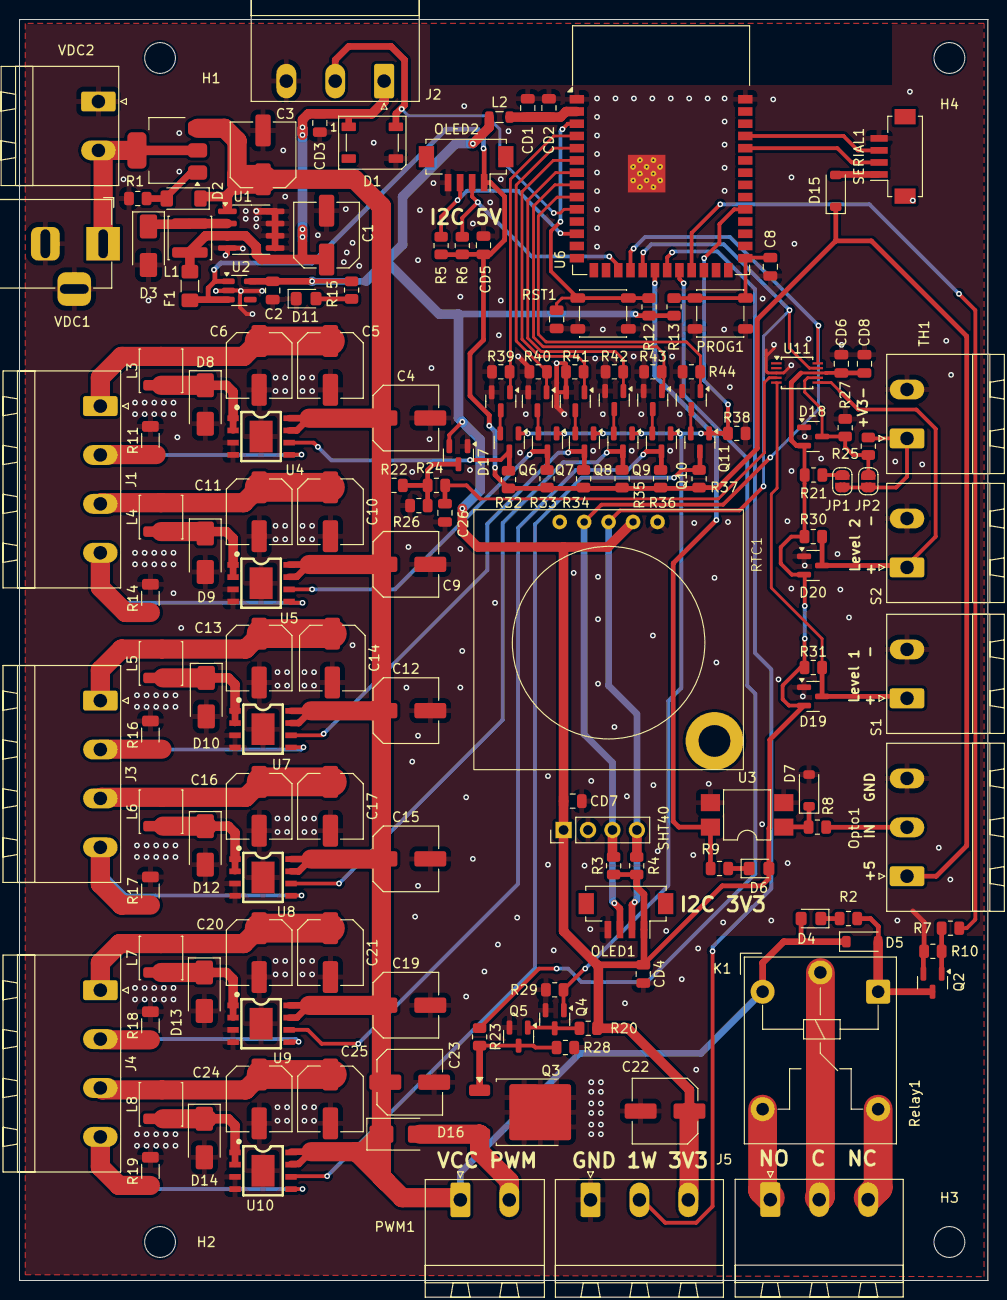
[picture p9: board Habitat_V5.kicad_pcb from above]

Board: 2 copper layers, 100.6 x 131.0 mm, 161 parts (0 on the bottom side), 80 nets.

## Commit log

2020-06-23 First push
    Primeira versão do esquemático para testes
2020-07-03 Update modulo de acionamento.dch
    Esquemático definitivo
2020-07-03 Backup
    Major layout wiring
2020-07-04 Layout V1.0
    Versão completa submetida para revisão
2020-07-04 Adição do Encoder
2020-07-06 Conector HB-9500
    Atualização de todos os conectores de potência;
    Nova malha de potência;
    Redução de mosfets redundantes;
    Relay alterado local na placa de estufa;
    Relays em curto alterados (para NO);
2020-07-11 Atualização dos conectores, espaçamento métrico
    Entrada de potência alterada KRE2 5mm para KF7.62
    PCB redimensionada de acordo
    Todas as dimensões no sistema métrico
    Grid e largura das trilhas em imperial
    Tamanho final: 105x109mm
    Furos M3 em (3.5,105), (80,105), (25,3.5)
2020-07-11 Gerber commit
    Posicionamento da logo no botton silk
    [BoardOutline.gbr, Bottom.gbr, BottomAssy.gbr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]
2020-07-11 Gerber com silk atualizada
2020-07-16 Step files and silk
    Pra modelagem 3D
    [HabitatControl-noholes.step, HabitatControl.step]
2020-08-06 Correção de tamanho dos furos pro BS9500
2023-03-22 V2 submited for review
    5x 12V 3A open drain PWM channels
    5x 3V3 outputs for external driver
    2x Relay
    1x I2C Temperature sensor
    1x I2C output (display)
    1x 5V 2A output (cooling fan)
2023-03-23 Rework on Power traces
    PVin line thickness 70 -> 90
    GND vias rearranjed
2023-03-23 Final revision before production
    [HabitatControl-noholes.step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]
2023-03-30 Habitat_V2_sanity-check
    Update before factory submission
    *Replaced 7.62mm header to barrier block;
    * Added varistor to AC line;
    * External panel fuse is expected;
2023-03-30 Sanity check before factory
    [habitatV2_BOM - LCSC.csv, habitatV2_BOM.csv, habitatV2_PNP.csv]
2023-04-10 Thermal and network rework
    Switched power mosfets to SOT-89;
    ESP antenna moved to board edge;
    Added optocoupled level-shifter as additional module.
2023-04-14 Heatsink update
    Added copper planes to act as heatsinks. Not great, not terrible
2023-12-21 V3 schematic and layout
2023-12-21 V3 update
    [BoM.csv, PnP.csv]
2023-12-22 HArdware update
    [BoM.csv, PnP.csv]
2024-02-26 Hardware fixes
    * Altered 2k2 resistors to 3k3
    * Corrected reverse voltage protection
    * Swapped B540C diodes for SS14
    * Swapped 47uH 3A inductor for 33uH 1A
2024-06-18 Added series limiting resistor for inverters
2025-07-17 Added V5 for ESP32
    [Habitat_V5.kicad_pcb, Habitat_V5.kicad_sch, modules.kicad_sch]
2025-07-18 Current update
    [Habitat_V5.kicad_pcb, Habitat_V5.kicad_sch, modules.kicad_sch]
2025-07-23 Updated PCB and Schematic
    [Habitat_V5.kicad_pcb, Habitat_V5.kicad_sch, modules.kicad_sch]
2025-07-24 Validation pre fab
    Pls check
    [Habitat_V5.kicad_pcb, Habitat_V5.kicad_sch, bom.csv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]
2025-07-24 Added final schematic PDF
    To do: correct GPIO pinout docs
2025-07-24 Review for production
    [Habitat_V5.kicad_pcb, Habitat_V5.kicad_sch, modules.kicad_sch]
2025-07-28 Files for production
    [Habitat_V5.kicad_pcb, Habitat_V5.kicad_sch, bom.csv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]
